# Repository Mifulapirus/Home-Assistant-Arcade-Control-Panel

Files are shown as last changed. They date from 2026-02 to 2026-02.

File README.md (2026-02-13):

# Home Assistant Control Panel

Home Assistant Control Panel project, including hardware designs and firmware for a smart home interface.

## Project Structure

- **Hardware/** - KiCad PCB designs and schematics
  - `HA Deck 0.1/` - Initial ESP8266-based prototype
  - `HA Deck 1.0/` - Current ESP32-based design
- **Software/** - ESPHome firmware configuration
  - Complete firmware for HA Deck 1.0
  - Setup guides and example automations

## Hardware Versions

### Version 0.1
- Based on **Wemos D1 Mini** (ESP8266)
- Initial prototype design
- KiCad project files located in `Hardware/HA Deck 0.1`

### Version 1.0 (Current Development)
- Based on **ESP32-WROOM-32** module
- Hardware upgrade driven by I/O requirements:
  - 5 arcade buttons with individual LEDs
  - 1.3" OLED I2C display
  - DHT22 temperature/humidity sensor
  - RCWL-0516 motion sensor
  - Buzzer for audio feedback
- KiCad project files located in `Hardware/HA Deck 1.0`
- Firmware located in `Software/`

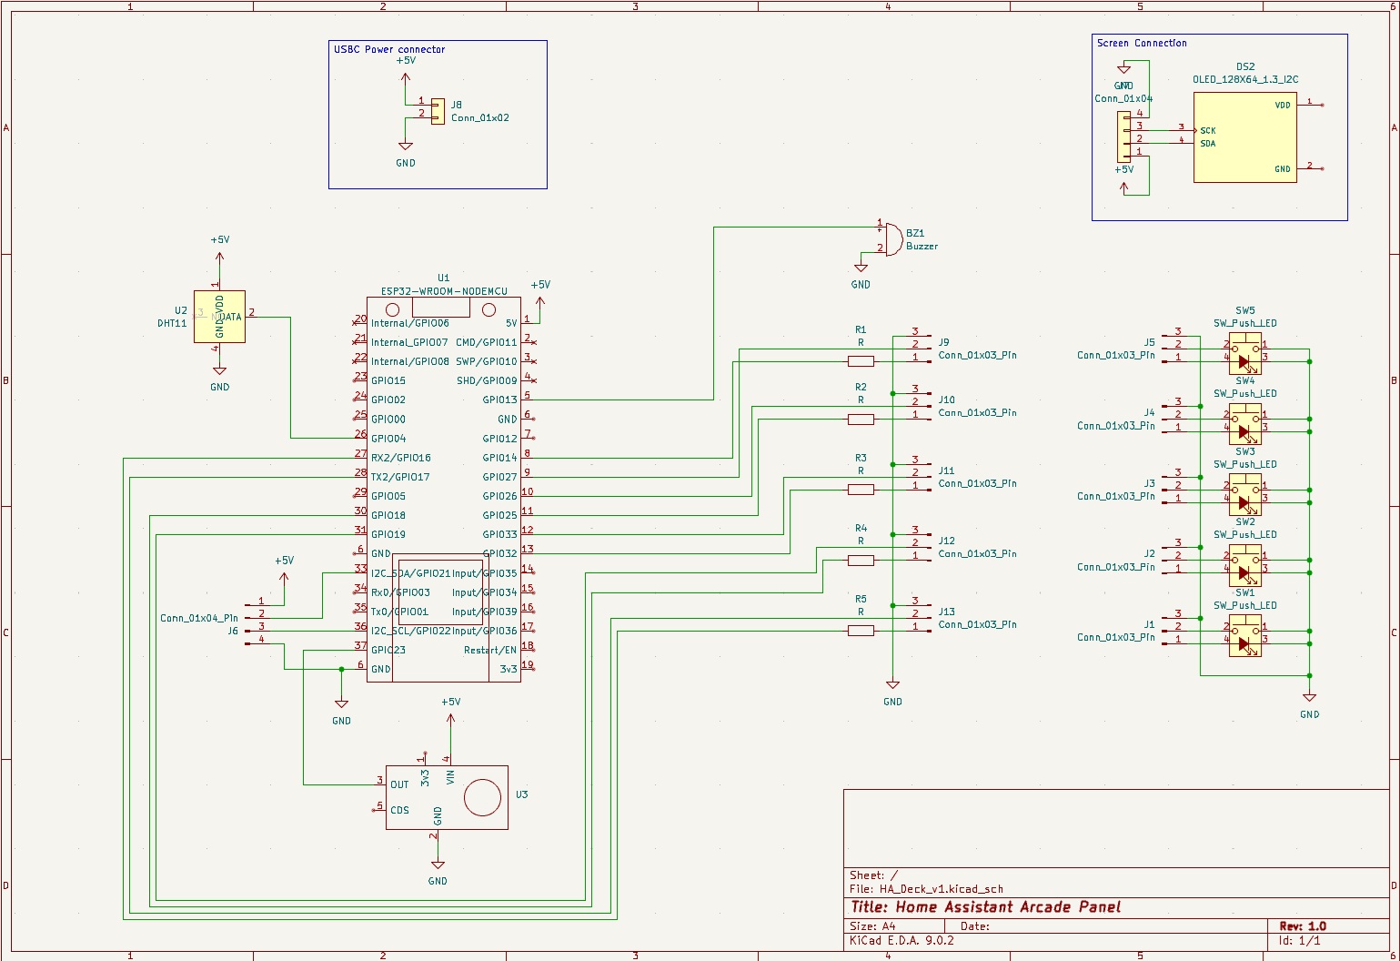
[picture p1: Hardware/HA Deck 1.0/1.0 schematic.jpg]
HA Deck v1.0 Schematic


## Firmware

- **ESPHome** - Used for firmware development and Home Assistant integration
- Enables easy configuration and OTA updates
- Native Home Assistant API support
- Color-coded buttons (Blue, Green, Red, White, Yellow)
- Custom display messages
- 10 buzzer sound patterns
- Full sensor integration

## Technologies Used

- KiCad for PCB design
- ESP32-WROOM-32 module (Version 1.0)
- Wemos D1 Mini / ESP8266 (Version 0.1)
- ESPHome firmware framework
- Home Assistant integration

## Getting Started

### Hardware
1. Open KiCad project files in `Hardware/HA Deck 1.0/`
2. Review schematic and PCB layout
3. Export Gerber files for fabrication

### Firmware
1. Navigate to `Software/` directory
2. Follow instructions in `ESPHOME_SETUP.md`
3. Configure `secrets.yaml` with your WiFi credentials
4. Upload firmware to ESP32

## Deployment

1. Fabricate the PCB using exported Gerber files
2. Assemble components according to schematic
3. Flash ESPHome firmware via USB
4. Device auto-discovers in Home Assistant
5. Configure automations and integrations

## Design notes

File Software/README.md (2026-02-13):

# Software - HA Arcade Panel Firmware

ESPHome firmware configuration for the Home Assistant Arcade Control Panel.

## Files

- **[ha_deck_v1.yaml](ha_deck_v1.yaml)** - Main ESPHome configuration file
- **[secrets.yaml](secrets.yaml)** - Template for WiFi credentials and API keys
- **[ESPHOME_SETUP.md](ESPHOME_SETUP.md)** - Complete setup and installation guide

## Hardware Version

This firmware is designed for **HA Deck 1.0** hardware.

## Quick Start

1. Copy `secrets.yaml` to your ESPHome config directory
2. Edit `secrets.yaml` with your WiFi credentials
3. Upload `ha_deck_v1.yaml` to your ESP32 via USB:
   ```bash
   esphome run ha_deck_v1.yaml
   ```
4. After first upload, updates can be done wirelessly (OTA)

## Features

### Device Information
- **Hardware Version Entity**: Displays "HA Deck 1.0" in Home Assistant

### User Interface
- **5 Color-Coded Buttons**: Blue, Green, Red, White, Yellow
- **5 Individual LEDs**: One for each button with independent control
- **OLED Display**: 1.3" I2C display showing time, temperature, and custom messages
- **Buzzer**: 10 pre-programmed sound patterns

### Sensors
- **DHT22**: Temperature and humidity monitoring
- **RCWL-0516**: Motion detection
- **Calculated Sensors**: Heat index, dew point
- **WiFi Signal**: Network strength monitoring

### Services

#### Display Custom Text
```yaml
service: esphome.ha_arcade_panel_display_text
data:
  text: "Hello!"
  duration: 5000
  font_size: 2
```

#### Play Buzzer Sequence
```yaml
service: esphome.ha_arcade_panel_play_buzzer_sequence
data:
  sequence: 1  # 1-10
```

## Pin Mapping (HA Deck 1.0)

| Component | GPIO | Function |
|---|---|---|
| Blue Button | GPIO17 | Input with pull-up |
| Green Button | GPIO19 | Input with pull-up |
| Red Button | GPIO33 | Input with pull-up |
| White Button | GPIO26 | Input with pull-up |
| Yellow Button | GPIO27 | Input with pull-up |
| Blue LED | GPIO16 | Output |
| Green LED | GPIO18 | Output |
| Red LED | GPIO32 | Output |
| White LED | GPIO25 | Output |
| Yellow LED | GPIO14 | Output |
| OLED SDA | GPIO21 | I2C Data |
| OLED SCL | GPIO22 | I2C Clock |
| DHT22 | GPIO04 | 1-Wire Data |
| RCWL-0516 | GPIO23 | Digital Input |
| Buzzer | GPIO13 | PWM Output |

## Documentation

See [ESPHOME_SETUP.md](ESPHOME_SETUP.md) for:
- Detailed installation instructions
- Home Assistant integration guide
- Example automations
- Troubleshooting tips
- Configuration customization

## Related Hardware

Hardware design files are located in: `../Hardware/HA Deck 1.0/`

---

*Part of the Home Assistant Control Panel project*

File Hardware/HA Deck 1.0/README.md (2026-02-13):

# HA Deck v1.0 - Hardware Documentation

Home Assistant Control Deck Version 1.0 with ESP32-WROOM-32

## Hardware Overview

### Microcontroller
- **ESP32-WROOM-32** (NodeMCU Dev Board)
- Dual-core 240 MHz processor
- Built-in WiFi and Bluetooth
- 3.3V logic level

### Components

#### User Interface
- **5× Arcade Style Buttons** - User input controls
- **5× LEDs** - Individual button illumination (one per button)
- **1.3" OLED I2C Display** - Status and information display
- **Buzzer** - Audio feedback

#### Sensors
- **DHT22** - Temperature and humidity sensor
- **RCWL-0516** - Microwave radar motion sensor

## Pin Assignment

### Buttons (Digital Input with Internal Pull-ups)
| Component | GPIO Pin | Notes |
|---|---|---|
| Button 1  | GPIO17 | Active LOW |
| Button 2  | GPIO19 | Active LOW |
| Button 3  | GPIO33 | Active LOW |
| Button 4  | GPIO26 | Active LOW |
| Button 5  | GPIO27 | Active LOW |

### LEDs (Digital Output)
| Component | GPIO Pin | Current Limiting |
|---|---|---|
| LED 1 | GPIO16 | 220Ω resistor |
| LED 2 | GPIO18 | 220Ω resistor |
| LED 3 | GPIO32 | 220Ω resistor |
| LED 4 | GPIO25 | 220Ω resistor |
| LED 5 | GPIO14 | 220Ω resistor |

### I2C Display
| Function | GPIO Pin | Notes |
|---|---|---|
| SDA | GPIO21 | Default I2C data |
| SCL | GPIO22 | Default I2C clock |

### Sensors
| Component | GPIO Pin | Function |
|---|---|---|
| DHT22 | GPIO04 | Digital data line |
| RCWL-0516 | GPIO23 | Digital output |

### Audio
| Component | GPIO Pin | Notes |
|---|---|---|
| Buzzer | GPIO13 | PWM capable |

### Power
- **VCC**: 3.3V for logic-level components
- **VIN**: 5V for sensors requiring higher voltage (DHT22, RCWL-0516)
- **GND**: Common ground

## Circuit Design Notes

### Button Configuration
- Buttons wired between GPIO and GND
- Internal pull-up resistors enabled in firmware (no external resistors needed)
- Debouncing handled in software

### LED Configuration
- Each LED in series with 220Ω current-limiting resistor
- Connected between GPIO and GND
- Forward voltage: ~2V, forward current: ~5-10mA

### I2C Display
- Standard I2C interface
- 3.3V compatible
- Address: Typically 0x3C or 0x3D

### Sensors
- **DHT22**: Single-wire digital interface, requires 3.3-5V
- **RCWL-0516**: 4-28V input, 3.3V compatible output

## Firmware

### Platform
- **ESPHome** - YAML configuration for Home Assistant integration

### Key Features
- Native Home Assistant API
- OTA (Over-The-Air) updates
- Real-time sensor monitoring
- Button press events
- LED control
- Display management

## GPIO Usage Summary

**Total GPIOs Used: 15**
- 5× Button inputs
- 5× LED outputs
- 2× I2C (shared bus)
- 1× DHT22 sensor
- 1× Motion sensor
- 1× Buzzer

**Available for expansion:** GPIO pins still available for future features

## Design Decisions

### Why ESP32-WROOM-32 over ESP8266?
The ESP32 was chosen over the ESP8266 (used in v0.1) due to:
- **GPIO count**: Need 13+ GPIOs for all components
- **Processing power**: Dual-core for better multitasking
- **Native I2C**: Better support for multiple I2C devices
- **Future expansion**: Additional pins available

### Pin Selection Rationale
- Avoided boot-sensitive pins (GPIO0, GPIO2, GPIO5, GPIO12, GPIO15)
- Used default I2C pins (GPIO21/22) for reliability
- Selected general-purpose pins for buttons (GPIO17, 19, 33, 26, 27) to enable internal pull-ups
- Distributed LED pins across available GPIOs (GPIO16, 18, 32, 25, 14)
- PWM-capable pins used for buzzer (GPIO13) and LED control
- Sensor pins carefully selected to avoid conflicts (GPIO04, GPIO23)

## Files in This Directory

- `HA_Deck_v1.kicad_pro` - KiCad project file
- `HA_Deck_v1.kicad_sch` - Schematic design
- `HA_Deck_v1.kicad_pcb` - PCB layout
- `README.md` - This file

**Firmware files are located in:** `../../Software/`

## Development Status

- [x] Component selection
- [x] Pin assignment
- [x] Initial schematic created
- [x] ESPHome firmware configuration
- [ ] Complete schematic wiring
- [ ] PCB layout design
- [ ] Footprint assignment
- [ ] PCB fabrication
- [ ] Assembly and testing

## Version History

**v1.0** (2026-02-07)
- Initial design with ESP32-WROOM-32
- 5 buttons with individual LEDs
- OLED display, DHT22, RCWL-0516 sensors
- Buzzer for audio feedback

---

*For main project information, see the [root README](../../README.md)*

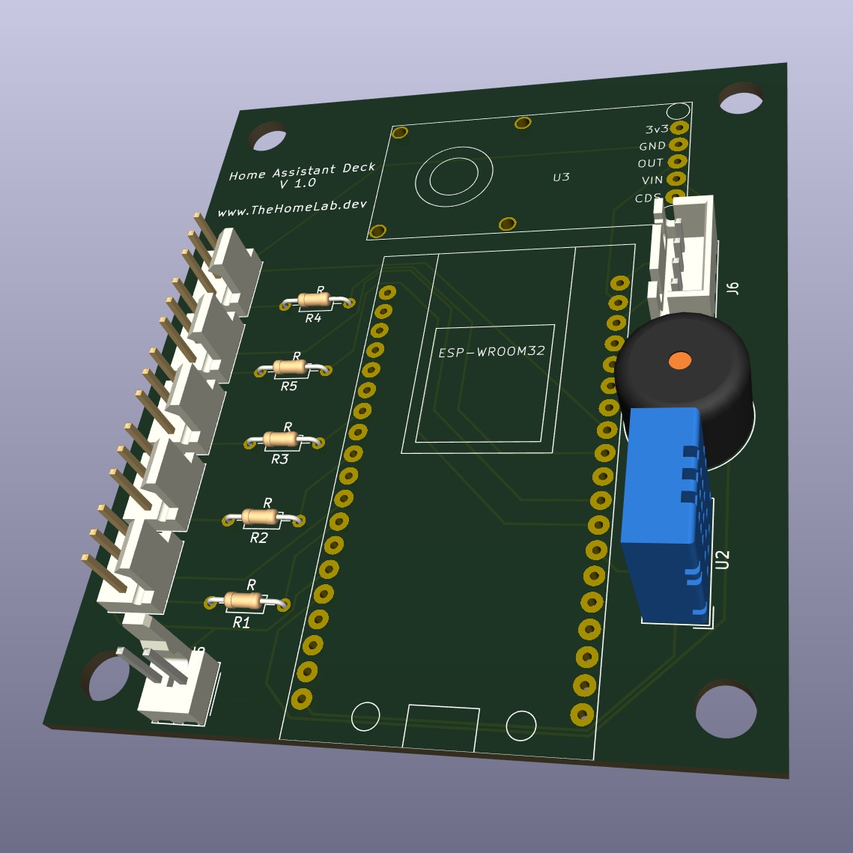
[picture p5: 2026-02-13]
Hardware/HA Deck 1.0/1.0 pcb 3d.jpg

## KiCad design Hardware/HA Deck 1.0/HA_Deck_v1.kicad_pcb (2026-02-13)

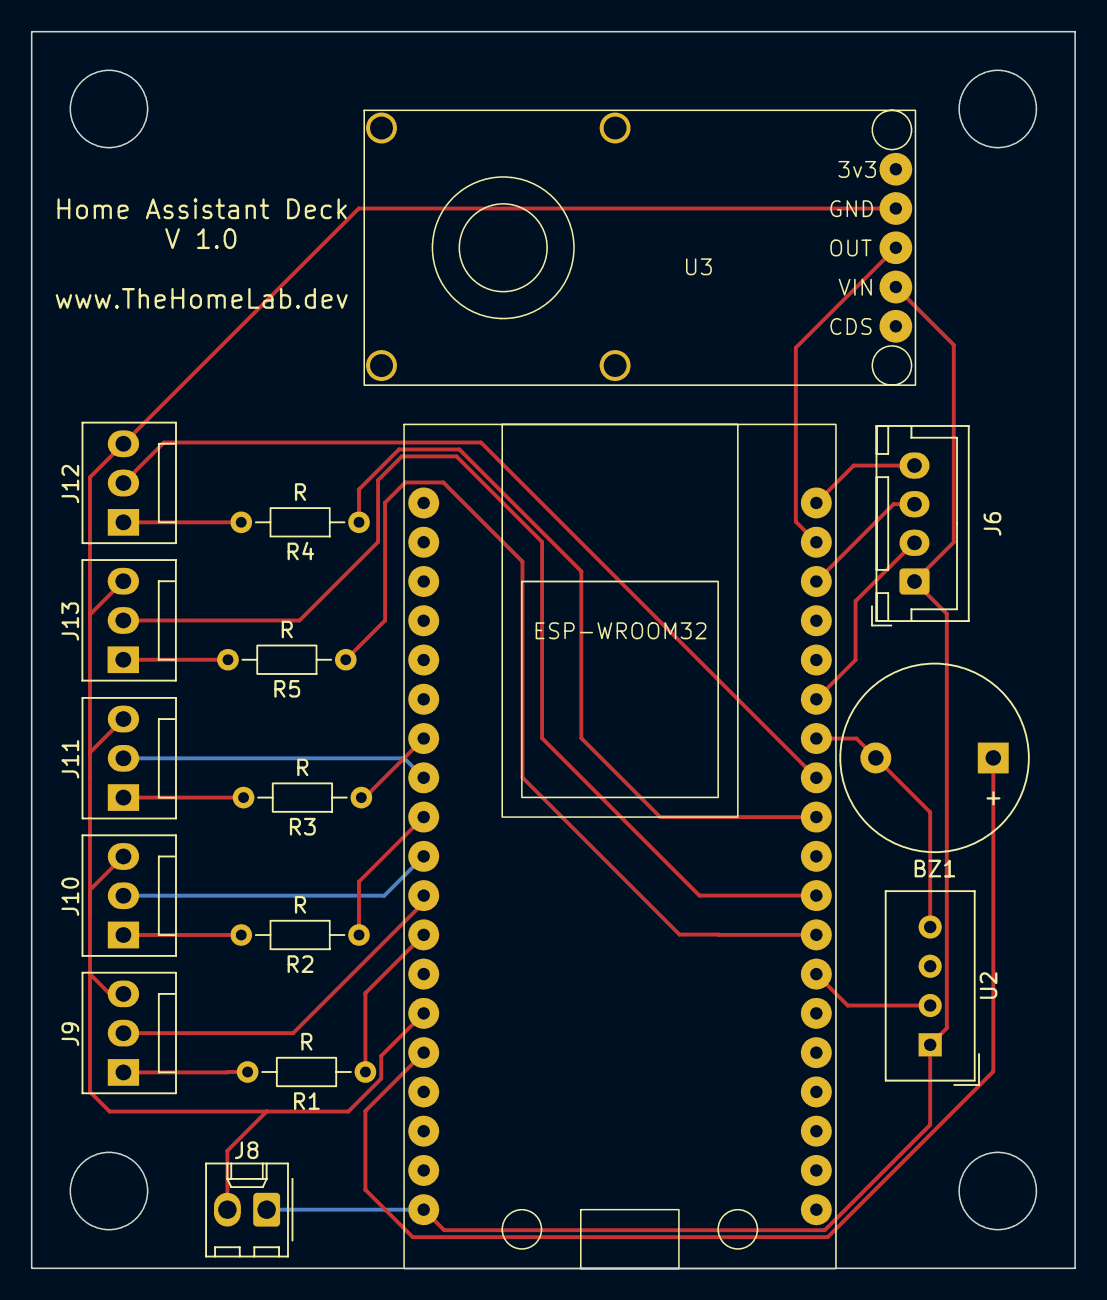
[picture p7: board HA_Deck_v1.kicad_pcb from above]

Board: 2 copper layers, 67.5 x 80.0 mm, 16 parts (0 on the bottom side), 22 nets.

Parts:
BZ1: Buzzer; Buzzer_12x9.5RM7.6
J6: Conn_01x04_Pin; JST_XH_B4B-XH-A_1x04_P2.50mm_Vertical
J8: Conn_01x02; Molex_KK-254_AE-6410-02A_1x02_P2.54mm_Vertical
J9, J10, J11, J12, J13: Conn_01x03_Pin; FanPinHeader_1x03_P2.54mm_Vertical
R1, R2, R3, R4, R5: R; R_Axial_DIN0204_L3.6mm_D1.6mm_P7.62mm_Horizontal
U1: ESP32-WROOM-NODEMCU; ESP32-Wroom-NodeMCU
U2: DHT11; Aosong_DHT11_5.5x12.0_P2.54mm
U3: RCWL-0516

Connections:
+5V: J6.1, J8.1, U1.1 (5V), U2.1 (VDD), U3.4 (VIN)
GND: BZ1.2 (-), J6.4, J8.2, J9.3, J10.3, J11.3, J12.3, J13.3, U1.6 (GND), U2.4 (GND), U3.2 (GND)
unnamed: BZ1.1 (+), U1.5 (GPIO13)
unnamed: J6.2, U1.33 (I2C_SDA/GPIO21)
unnamed: J6.3, U1.36 (I2C_SCL/GPIO22)
unnamed: J9.1, R1.2
unnamed: J9.2, U1.9 (GPIO27)
unnamed: J10.1, R2.2
unnamed: J10.2, U1.10 (GPIO26)
unnamed: J11.1, R3.2
unnamed: J11.2, U1.12 (GPIO33)
unnamed: J12.1, R4.2
unnamed: J12.2, U1.31 (GPIO19)
unnamed: J13.1, R5.2
unnamed: J13.2, U1.28 (TX2/GPIO17)
unnamed: U1.26 (GPIO04), U2.2 (DATA)
unnamed: R1.1, U1.8 (GPIO14)
unnamed: R4.1, U1.30 (GPIO18)
unnamed: U1.37 (GPIO23), U3.3 (OUT)
unnamed: R2.1, U1.11 (GPIO25)
unnamed: R3.1, U1.13 (GPIO32)
unnamed: R5.1, U1.27 (RX2/GPIO16)

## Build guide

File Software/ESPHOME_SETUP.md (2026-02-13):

# ESPHome Setup Guide for HA Deck v1.0

## Prerequisites

1. **ESPHome installed** (via Home Assistant Add-on or standalone)
2. **USB cable** to connect ESP32 to computer
3. **Home Assistant** instance running

## Installation Methods

### Method A: Home Assistant Add-on (Recommended)

If you're using ESPHome via Home Assistant add-on:

1. **Install ESPHome Add-on**
   - Settings → Add-ons → Add-on Store
   - Search "ESPHome" → Install
   - Start the add-on

2. **Open ESPHome Web UI**
   - Click "Open Web UI" in the add-on
   - Upload `ha_deck_v1.yaml` file
   - The add-on manages the config directory

3. **Configure Secrets**
   - In ESPHome Web UI, click the overflow menu (⋮) → Secrets
   - Enter your WiFi credentials
   - For API key, choose one of these options:
     - **Option A (Easiest)**: Leave blank and ESPHome generates it automatically on first compile
     - **Option B (Manual)**: Generate a key using Python and paste it:
       ```python
       import base64, os
       print(base64.b64encode(os.urandom(32)).decode())
       ```
       Run this in any Python environment and paste the output as the `api_encryption_key`
     - **Option C (Copy-paste)**: Use this example (recommended for testing):
       ```
       api_encryption_key: "TW93QXEzQmhWeUZzTW56RVhxNS9LaVVudHl0MVN3MVJ0bmc="
       ```
       ⚠️ **Note**: For production, generate your own key using Option B

4. **Upload to Device**
   - Connect ESP32 via USB
   - Click the device in ESPHome
   - Select "Install" → "Connect to this computer via USB"
   - Select your USB port

### Method B: Standalone ESPHome (Terminal)

If using standalone ESPHome installation:

1. **Install ESPHome**
   ```bash
   pip3 install esphome
   ```

2. **Generate API Encryption Key**
   
   Choose one of these methods:
   
   **Option A - Easiest (Auto-generate)**
   
   Just leave the key blank in secrets.yaml:
   ```yaml
   api_encryption_key: ""
   ```
   ESPHome will generate it automatically on first compile and display it in the logs.
   
   **Option B - Generate with Python** (recommended for production)
   
   ```bash
   python3 -c "import base64, os; print(base64.b64encode(os.urandom(32)).decode())"
   ```
   
   Copy the output and paste it into `secrets.yaml`
   
   **Option C - Manual Generation (OpenSSL)**
   
   If openssl is available:
   ```bash
   openssl rand -base64 32
   ```
   
   Copy the output into `secrets.yaml`

3. **Configure Secrets**
   
   Edit `secrets.yaml`:
   ```yaml
   wifi_ssid: "YourActualWiFiName"
   wifi_password: "YourActualWiFiPassword"
   api_encryption_key: "base64EncodedKey=="
   ota_password: "ChooseAStrongPassword"
   ap_password: "FallbackPassword"
   ```

4. **First Upload (via USB)**
   
   ```bash
   esphome run ha_deck_v1.yaml
   ```
   Select the USB serial port when prompted.

5. **Subsequent Updates (OTA)**
   
   After first upload, update wirelessly:
   ```bash
   esphome run ha_deck_v1.yaml
   ```
   Select the network device when prompted.

## Home Assistant Integration

### 1. Auto-Discovery

The device should appear in Home Assistant under **Settings → Devices & Services → ESPHome**

### 2. Manual Integration

If auto-discovery doesn't work:
1. Go to **Settings → Devices & Services**
2. Click **Add Integration**
3. Search for **ESPHome**
4. Enter the device IP address
5. Enter the encryption key from `secrets.yaml`

## Available Entities

### Buttons (Binary Sensors)
- `binary_sensor.blue_button`
- `binary_sensor.green_button`
- `binary_sensor.red_button`
- `binary_sensor.white_button`
- `binary_sensor.yellow_button`
- `binary_sensor.arcade_panel_motion`

### LEDs (Lights)
- `light.blue_led`
- `light.green_led`
- `light.red_led`
- `light.white_led`
- `light.yellow_led`

### Sensors
- `sensor.arcade_panel_temperature`
- `sensor.arcade_panel_humidity`
- `sensor.arcade_panel_heat_index`
- `sensor.arcade_panel_dew_point`
- `sensor.arcade_panel_wifi_signal`

### Text Sensors
- `text_sensor.hardware_version` - Displays "HA Deck 1.0"

### Services

#### Display Custom Text
```yaml
service: esphome.ha_arcade_panel_display_text
data:
  text: "Hello World!"
  duration: 5000  # milliseconds
  font_size: 2     # 1=small, 2=medium, 3=large
```

#### Play Buzzer Sequence
```yaml
service: esphome.ha_arcade_panel_play_buzzer_sequence
data:
  sequence: 1
```

**Available Sequences:**
1. Short beep (100ms)
2. Beep-beep (double tap)
3. Long beep (500ms)
4. Triple beep
5. Rising tone
6. Alert pattern
7. Success chirp
8. Error buzz
9. Doorbell
10. SOS pattern

## Example Automations

### Display Message on Button Press

```yaml
automation:
  - alias: "Blue Button Display Message"
    trigger:
      - platform: state
        entity_id: binary_sensor.blue_button
        to: 'on'
    action:
      - service: esphome.ha_arcade_panel_display_text
        data:
          text: "Blue Activated!"
          duration: 3000
          font_size: 2
      - service: esphome.ha_arcade_panel_play_buzzer_sequence
        data:
          sequence: 7
```

### Temperature Alert

```yaml
automation:
  - alias: "High Temperature Alert"
    trigger:
      - platform: numeric_state
        entity_id: sensor.arcade_panel_temperature
        above: 30
    action:
      - service: esphome.ha_arcade_panel_display_text
        data:
          text: "High Temp!"
          duration: 10000
          font_size: 3
      - service: esphome.ha_arcade_panel_play_buzzer_sequence
        data:
          sequence: 6
      - service: light.turn_on
        entity_id: light.red_led
```

### Motion Detection with Visual Feedback

```yaml
automation:
  - alias: "Motion Detected Feedback"
    trigger:
      - platform: state
        entity_id: binary_sensor.arcade_panel_motion
        to: 'on'
    action:
      - service: light.turn_on
        entity_id: light.white_led
      - service: esphome.ha_arcade_panel_play_buzzer_sequence
        data:
          sequence: 1
      - delay: '00:00:02'
      - service: light.turn_off
        entity_id: light.white_led
```

### LED Pattern on Startup

```yaml
automation:
  - alias: "Arcade Panel Startup Sequence"
    trigger:
      - platform: homeassistant
        event: start
    action:
      - service: light.turn_on
        entity_id: light.blue_led
      - delay: '00:00:00.2'
      - service: light.turn_on
        entity_id: light.green_led
      - delay: '00:00:00.2'
      - service: light.turn_on
        entity_id: light.red_led
      - delay: '00:00:00.2'
      - service: light.turn_on
        entity_id: light.white_led
      - delay: '00:00:00.2'
      - service: light.turn_on
        entity_id: light.yellow_led
      - delay: '00:00:01'
      - service: light.turn_off
        entity_id: 
          - light.blue_led
          - light.green_led
          - light.red_led
          - light.white_led
          - light.yellow_led
```

## Troubleshooting

### API Key Generation Issues

**"esphome" command not found**

This is normal if ESPHome isn't installed as a CLI tool. You have these options:

1. **Let ESPHome auto-generate** (Recommended for addon users)
   - Leave `api_encryption_key: ""` in secrets.yaml
   - ESPHome generates it on first compile
   - Check the logs to see the generated key

2. **Generate with Python** (Works anywhere)
   ```bash
   python3 -c "import base64, os; print(base64.b64encode(os.urandom(32)).decode())"
   ```
   Copy the output and paste into `secrets.yaml`

3. **Generate with PHP** (If you have PHP installed)
   ```bash
   php -r "echo base64_encode(random_bytes(32));"
   ```

4. **Use an online tool** (For testing only, not production)
   - https://generate.plus/en/base64
   - Generate 32 random bytes and base64 encode

### Display Not Working
- Check I2C address (0x3C or 0x3D)
- Try changing `model: "SH1106 128x64"` to `SSD1306_128X64`
- Enable I2C scan in logs to verify address

### Buttons Not Responding
- Verify internal pull-ups are enabled
- Check wiring: buttons between GPIO and GND
- Increase debounce in binary_sensor config if needed

### WiFi Connection Issues
- Check SSID and password in secrets.yaml
- Verify WiFi coverage in device location
- Use fallback AP mode to reconfigure

### OTA Updates Failing
- Ensure device is on same network
- Check firewall settings
- Try USB upload if OTA consistently fails

## Configuration Customization

### Change Timezone

The current config automatically gets timezone from Home Assistant:

```yaml
time:
  - platform: homeassistant
    id: ha_time
    timezone: "America/New_York"  # Gets your HA timezone
```

To override with a specific timezone:
```yaml
time:
  - platform: homeassistant
    id: ha_time
    timezone: "Europe/London"  # Your timezone
```

### Use NTP Instead of Home Assistant

If you prefer to get time from NTP (independent of Home Assistant):

```yaml
time:
  - platform: sntp
    id: ha_time
    timezone: "America/New_York"
    servers:
      - 0.pool.ntp.org
      - 1.pool.ntp.org
```

### Adjust Display Update Rate
Change `update_interval` in display component:
```yaml
display:
  - platform: ssd1306_i2c
    update_interval: 500ms  # Faster updates
```

### Change Page Cycle Time
Modify the interval:
```yaml
interval:
  - interval: 10s  # Show each page for 10 seconds
```

### Adjust DHT22 Update Frequency
```yaml
sensor:
  - platform: dht
    update_interval: 60s  # Update every minute
```

## Hardware Notes

- All LEDs use 220Ω current-limiting resistors
- Buttons use internal ESP32 pull-up resistors (no external resistors needed)
- DHT22 sensor may need a 4.7kΩ pull-up resistor on data line (depends on module)
- OLED display is 3.3V compatible

## Support

For issues or questions:
- Check ESPHome documentation: https://esphome.io
- Review logs: `esphome logs ha_deck_v1.yaml`
- See project README in parent directory

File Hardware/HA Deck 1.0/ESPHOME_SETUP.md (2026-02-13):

# ESPHome Setup Guide for HA Deck v1.0

## Prerequisites

1. **ESPHome installed** (via Home Assistant Add-on or standalone)
2. **USB cable** to connect ESP32 to computer
3. **Home Assistant** instance running

## Initial Setup

### 1. Generate Encryption Key

Run this command to generate your API encryption key:
```bash
esphome -s api_key $(openssl rand -base64 32) compile ha_deck_v1.yaml
```

Or let ESPHome generate it automatically on first compile.

### 2. Configure Secrets

Edit `secrets.yaml` with your actual values:

```yaml
wifi_ssid: "YourActualWiFiName"
wifi_password: "YourActualWiFiPassword"
api_encryption_key: "base64EncodedKey=="
ota_password: "ChooseAStrongPassword"
ap_password: "FallbackPassword"
```

### 3. First Upload (via USB)

```bash
esphome run ha_deck_v1.yaml
```

Select the USB serial port when prompted.

### 4. Subsequent Updates (OTA)

After the first upload, you can update wirelessly:

```bash
esphome run ha_deck_v1.yaml
```

Select the network device when prompted.

## Home Assistant Integration

### 1. Auto-Discovery

The device should appear in Home Assistant under **Settings → Devices & Services → ESPHome**

### 2. Manual Integration

If auto-discovery doesn't work:
1. Go to **Settings → Devices & Services**
2. Click **Add Integration**
3. Search for **ESPHome**
4. Enter the device IP address
5. Enter the encryption key from `secrets.yaml`

## Available Entities

### Buttons (Binary Sensors)
- `binary_sensor.blue_button`
- `binary_sensor.green_button`
- `binary_sensor.red_button`
- `binary_sensor.white_button`
- `binary_sensor.yellow_button`
- `binary_sensor.arcade_panel_motion`

### LEDs (Lights)
- `light.blue_led`
- `light.green_led`
- `light.red_led`
- `light.white_led`
- `light.yellow_led`

### Sensors
- `sensor.arcade_panel_temperature`
- `sensor.arcade_panel_humidity`
- `sensor.arcade_panel_heat_index`
- `sensor.arcade_panel_dew_point`
- `sensor.arcade_panel_wifi_signal`

### Services

#### Display Custom Text
```yaml
service: esphome.ha_arcade_panel_display_text
data:
  text: "Hello World!"
  duration: 5000  # milliseconds
  font_size: 2     # 1=small, 2=medium, 3=large
```

#### Play Buzzer Sequence
```yaml
service: esphome.ha_arcade_panel_play_buzzer_sequence
data:
  sequence: 1
```

**Available Sequences:**
1. Short beep (100ms)
2. Beep-beep (double tap)
3. Long beep (500ms)
4. Triple beep
5. Rising tone
6. Alert pattern
7. Success chirp
8. Error buzz
9. Doorbell
10. SOS pattern

## Example Automations

### Display Message on Button Press

```yaml
automation:
  - alias: "Blue Button Display Message"
    trigger:
      - platform: state
        entity_id: binary_sensor.blue_button
        to: 'on'
    action:
      - service: esphome.ha_arcade_panel_display_text
        data:
          text: "Blue Activated!"
          duration: 3000
          font_size: 2
      - service: esphome.ha_arcade_panel_play_buzzer_sequence
        data:
          sequence: 7
```

### Temperature Alert

```yaml
automation:
  - alias: "High Temperature Alert"
    trigger:
      - platform: numeric_state
        entity_id: sensor.arcade_panel_temperature
        above: 30
    action:
      - service: esphome.ha_arcade_panel_display_text
        data:
          text: "High Temp!"
          duration: 10000
          font_size: 3
      - service: esphome.ha_arcade_panel_play_buzzer_sequence
        data:
          sequence: 6
      - service: light.turn_on
        entity_id: light.red_led
```

### Motion Detection with Visual Feedback

```yaml
automation:
  - alias: "Motion Detected Feedback"
    trigger:
      - platform: state
        entity_id: binary_sensor.arcade_panel_motion
        to: 'on'
    action:
      - service: light.turn_on
        entity_id: light.white_led
      - service: esphome.ha_arcade_panel_play_buzzer_sequence
        data:
          sequence: 1
      - delay: '00:00:02'
      - service: light.turn_off
        entity_id: light.white_led
```

### LED Pattern on Startup

```yaml
automation:
  - alias: "Arcade Panel Startup Sequence"
    trigger:
      - platform: homeassistant
        event: start
    action:
      - service: light.turn_on
        entity_id: light.blue_led
      - delay: '00:00:00.2'
      - service: light.turn_on
        entity_id: light.green_led
      - delay: '00:00:00.2'
      - service: light.turn_on
        entity_id: light.red_led
      - delay: '00:00:00.2'
      - service: light.turn_on
        entity_id: light.white_led
      - delay: '00:00:00.2'
      - service: light.turn_on
        entity_id: light.yellow_led
      - delay: '00:00:01'
      - service: light.turn_off
        entity_id: 
          - light.blue_led
          - light.green_led
          - light.red_led
          - light.white_led
          - light.yellow_led
```

## Troubleshooting

### Display Not Working
- Check I2C address (0x3C or 0x3D)
- Try changing `model: "SH1106 128x64"` to `SSD1306_128X64`
- Enable I2C scan in logs to verify address

### Buttons Not Responding
- Verify internal pull-ups are enabled
- Check wiring: buttons between GPIO and GND
- Increase debounce in binary_sensor config if needed

### WiFi Connection Issues
- Check SSID and password in secrets.yaml
- Verify WiFi coverage in device location
- Use fallback AP mode to reconfigure

### OTA Updates Failing
- Ensure device is on same network
- Check firewall settings
- Try USB upload if OTA consistently fails

## Configuration Customization

### Change Timezone
Edit the `time:` component:
```yaml
time:
  - platform: homeassistant
    id: ha_time
    timezone: "Europe/London"  # Your timezone
```

### Adjust Display Update Rate
Change `update_interval` in display component:
```yaml
display:
  - platform: ssd1306_i2c
    update_interval: 500ms  # Faster updates
```

### Change Page Cycle Time
Modify the interval:
```yaml
interval:
  - interval: 10s  # Show each page for 10 seconds
```

### Adjust DHT22 Update Frequency
```yaml
sensor:
  - platform: dht
    update_interval: 60s  # Update every minute
```

## Hardware Notes

- All LEDs use 220Ω current-limiting resistors
- Buttons use internal ESP32 pull-up resistors (no external resistors needed)
- DHT22 sensor may need a 4.7kΩ pull-up resistor on data line (depends on module)
- OLED display is 3.3V compatible

## Support

For issues or questions:
- Check ESPHome documentation: https://esphome.io
- Review logs: `esphome logs ha_deck_v1.yaml`
- See project README in parent directory

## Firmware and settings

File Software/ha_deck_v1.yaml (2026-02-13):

esphome:
  name: ha-arcade-panel
  friendly_name: HA Arcade Panel
  on_boot:
    priority: -100
    then:
      - display.page.show: page_time
      - lambda: |-
          id(display_mode) = 0;

esp32:
  board: lolin32
  framework:
    type: arduino

# Enable logging
logger:
  level: INFO

# Enable Home Assistant API
api:
  encryption:
    key: !secret api_encryption_key

ota:
  - platform: esphome
    password: "cujoandcoqueta"

wifi:
  ssid: !secret wifi_ssid
  password: !secret wifi_password
  
  # Enable fallback hotspot in case WiFi connection fails
  ap:
    ssid: "HA-Arcade-Panel"
    password: !secret ap_password 

captive_portal:

# Global variables for display management
globals:
  - id: display_mode
    type: int
    restore_value: no
    initial_value: '0'  # 0=time, 1=temp, 2=custom
  - id: custom_text
    type: std::string
    restore_value: no
    initial_value: '""'
  - id: text_duration
    type: int
    restore_value: no
    initial_value: '5000'
  - id: text_font_size
    type: int
    restore_value: no
    initial_value: '1'  # 1=small, 2=medium, 3=large
  - id: text_start_time
    type: unsigned long
    restore_value: no
    initial_value: '0'
  - id: scroll_offset
    type: int
    restore_value: no
    initial_value: '0'
  - id: scroll_speed
    type: int
    restore_value: no
    initial_value: '3'

# I2C Bus for OLED Display
i2c:
  sda: GPIO21
  scl: GPIO22
  scan: true
  id: bus_a

# Fonts for display
font:
  - file: "gfonts://Roboto"
    id: font_small
    size: 12
  - file: "gfonts://Roboto"
    id: font_medium
    size: 16
  - file: "gfonts://Roboto"
    id: font_large
    size: 24
  - file: "gfonts://Roboto"
    id: font_time
    size: 28

# 1.3" OLED Display (SH1106 or SSD1306)
display:
  - platform: ssd1306_i2c
    model: "SH1106 128x64"  # Change to SSD1306_128X64 if using SSD1306
    id: display_page
    address: 0x3C  # Standard address - check I2C scan logs for actual address
    update_interval: 100ms  # Fast refresh for smooth text scrolling
    pages:
      - id: page_time
        lambda: |-
          it.strftime(64, 20, id(font_time), TextAlign::CENTER, "%H:%M", id(ha_time).now());
          it.strftime(64, 45, id(font_small), TextAlign::CENTER, "%d %b %Y", id(ha_time).now());
      
      - id: page_temp
        lambda: |-
          it.printf(64, 10, id(font_medium), TextAlign::CENTER, "Temperature");
          if (id(dht_temperature).has_state()) {
            it.printf(64, 30, id(font_large), TextAlign::CENTER, "%.1f°C", id(dht_temperature).state);
          }
          if (id(dht_humidity).has_state()) {
            it.printf(64, 52, id(font_small), TextAlign::CENTER, "Humidity: %.0f%%", id(dht_humidity).state);
          }
      
      - id: page_custom
        lambda: |-
          // Check if custom text display duration has expired (convert seconds to ms)
          if (millis() - id(text_start_time) > (id(text_duration) * 1000)) {
            id(display_mode) = 0;
            id(scroll_offset) = 0;
            return;
          }
          
          // Select font based on text_font_size
          auto font = id(font_small);
          if (id(text_font_size) == 2) font = id(font_medium);
          else if (id(text_font_size) == 3) font = id(font_large);
          
          // Measure text width
          int x1 = 0, y1 = 0, text_width = 0, text_height = 0;
          it.get_text_bounds(0, 0, id(custom_text).c_str(), font, TextAlign::TOP_LEFT, &x1, &y1, &text_width, &text_height);
          
          // If text fits on screen, center it
          if (text_width <= 128) {
            it.printf(64, 32, font, TextAlign::CENTER, "%s", id(custom_text).c_str());
            id(scroll_offset) = 0;
          } else {
            // Scroll text from right to left
            int x_pos = 128 - id(scroll_offset);
            it.printf(x_pos, 32, font, TextAlign::TOP_LEFT, "%s", id(custom_text).c_str());
            
            // Update scroll offset (moves scroll_speed pixels per update)
            id(scroll_offset) += id(scroll_speed);
            
            // Reset when text has scrolled off screen
            if (id(scroll_offset) > text_width + 128) {
              id(scroll_offset) = 0;
            }
          }

# Time component for display
time:
  - platform: homeassistant
    id: ha_time
    timezone: "America/New_York"  # Change to your timezone

# Interval to cycle between display pages
interval:
  - interval: 5s
    then:
      - lambda: |-
          if (id(display_mode) == 0) {
            // Switch from time to temperature
            id(display_page).show_page(id(page_temp));
            id(display_mode) = 1;
          } else if (id(display_mode) == 1) {
            // Switch from temperature to time
            id(display_page).show_page(id(page_time));
            id(display_mode) = 0;
          }
          // mode 2 (custom text) doesn't auto-cycle
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

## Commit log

2026-02-13 First release
    [HA Deck.kicad_pcb, HA Deck.kicad_sch, HA_Deck_v1.kicad_pcb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]
2026-02-13 updated sw
    [HA_Deck_v1.kicad_sch]
